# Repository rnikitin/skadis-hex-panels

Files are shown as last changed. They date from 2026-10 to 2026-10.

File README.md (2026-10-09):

# Hexagonal SKÅDIS-compatible panels



**Start in [PRINT_THIS](PRINT_THIS/README.md).** This folder contains only the current printable version. Earlier prototypes are under `archive/`.

| File | Use |
|---|---|
| [S01_complete_kit_PETG_P2S.3mf](PRINT_THIS/S01_complete_kit_PETG_P2S.3mf) | Ready Bambu Studio project: two panels, eight mounts and one flat jig |
| [S01_panel_PLA_P2S.3mf](PRINT_THIS/S01_panel_PLA_P2S.3mf) | Ready Bambu Studio project for the identical panel in PLA |
| [S01_panel.stl](PRINT_THIS/S01_panel.stl) | Hex panel |
| [S01_wall_mount_2p2.stl](PRINT_THIS/S01_wall_mount_2p2.stl) | Wall mount for the selected 3 × 16 mm self-tapper |
| [S01_alignment_jig_5p2.stl](PRINT_THIS/S01_alignment_jig_5p2.stl) | Flat removable jig, 5.2 mm fit and 4.4 mm insertion depth |

All plates print without supports. See [assembly](docs/assembly.md), [hardware](docs/hardware.md), and [STEP models](cad/) for details.

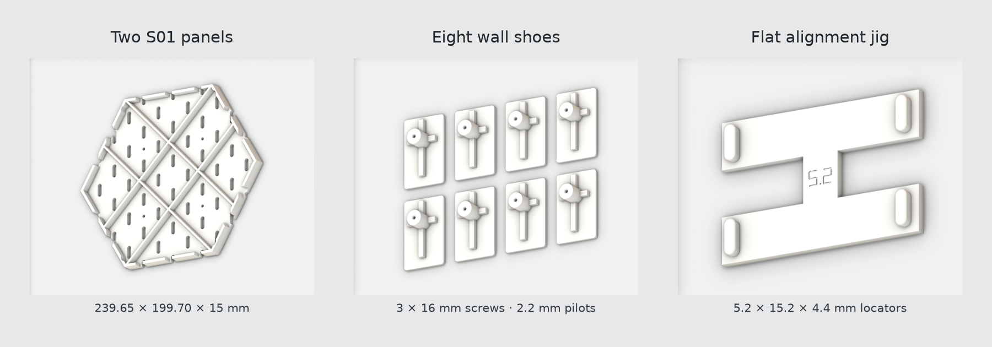
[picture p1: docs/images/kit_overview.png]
Current print kit


## Panel renders

| Front | Rear, tilted to show all four ribs |
|---|---|
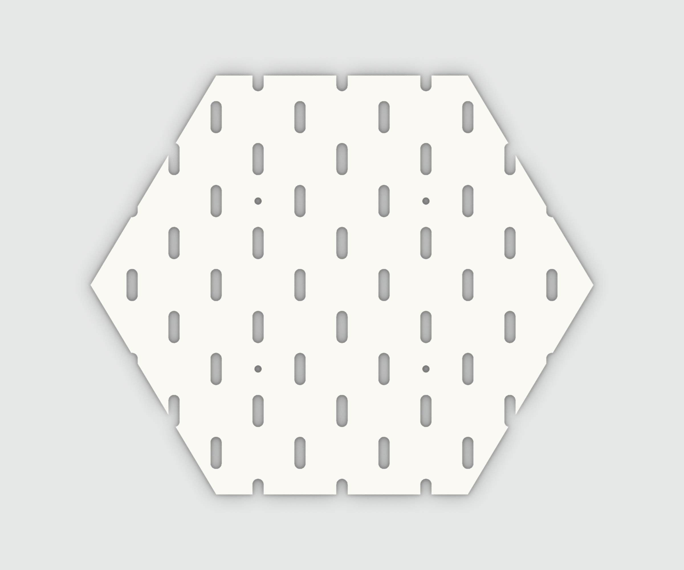
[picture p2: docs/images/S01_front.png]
One S01 panel from the front
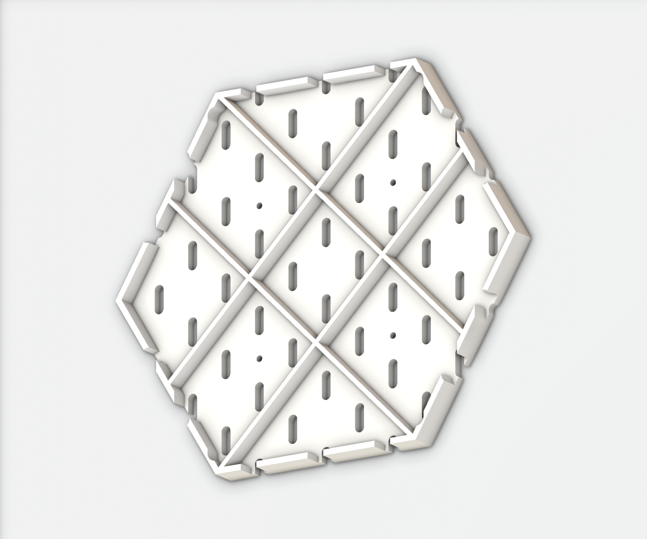
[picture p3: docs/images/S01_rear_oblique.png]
S01 rear ribs at an oblique angle
|  |  |

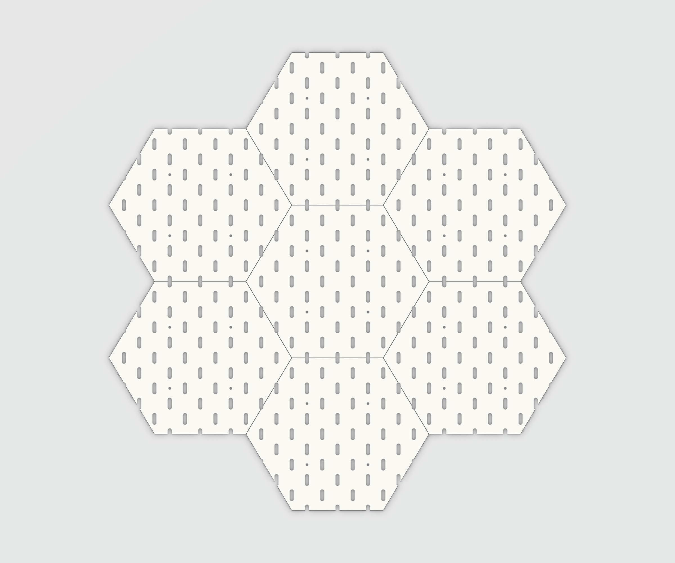
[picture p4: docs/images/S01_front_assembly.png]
Seven S01 panels joined on the same slot lattice


Matte-white studio renders of the final printable STL geometry. The seven-panel layout uses the nominal 0.3 mm seams, with subtle edge accents for visibility at smaller display sizes. Full-resolution images are in `docs/images`.

Each panel is approximately **239.65 × 199.70 × 15 mm**. Panel faces are 5 mm thick; slots are 5.3 × 15.3 mm. Current slicer settings are 0.2 mm layers, four walls and 100% infill. Each PETG panel estimates 6 h 45 min / 239 g. PLA and PETG projects are separate because the installed command-line slicer failed on a combined-material run. Both delivered projects were successfully sliced and checked.

Print one or two panels in the chosen material, then the PETG hardware plates. The PLA project is an alternative to a PETG panel plate. No additional small calibration print is required for this iteration.

## Build from source

Python 3.12 is the supported baseline:

```sh
uv sync --extra dev
uv run skadis-hex build --output build/full-kit
uv run skadis-hex validate --output build/full-kit
uv run pytest -q
# Requires a separately installed Bambu Studio:
uv run skadis-hex slice --output build/full-kit
```

The build produces three STL parts, STEP parts and mounted assemblies, geometry-only 3MFs and dimension records. Slicing produces the native PETG and PLA projects, plate previews and verification reports. Use `--slicer /path/to/BambuStudio` on other installations. No command sends a print job.

Alternatively, install the package with `python -m pip install -e '.[dev]'` in a Python 3.12 virtual environment.

## Verification status

| Item | Status |
|---|---|
| Continuous slot lattice and two-row spacing | Checked geometrically |
| Connected watertight full-kit meshes | Checked |
| Six jig seam placements, short locators and screw-head clearance | Checked geometrically |
| Native PETG/PLA material assignments, supports, plate bounds and toolpaths | Checked |
| 5.2 mm PETG fit strip | Selected by the user after printing |
| Increased jig depth and four-point fit | Full-size print pending |
| Selected 2.2 mm screw pilot | User-selected; full assembly test pending |
| Accessory insertion, tape on wallpaper and full-panel load rating | Not yet established |

The historical 3 kg / 100 mm study used earlier geometry and idealized PLA/support conditions. It is not a load rating for the current panel or adhesive mounting.

## Project map and history

```text
PRINT_THIS/           Current STL and ready Bambu Studio files only
cad/                  Current STEP parts and mounted assemblies
verification/current/ Checks, previews and SHA-256 manifest
src/skadis_hex/       Parametric geometry and build/slicing tools
docs/                 English printing, hardware and design documentation
archive/              Superseded prototypes and experiments
analysis/v3/          Historical stiffness comparison
```

The rear-open hidden key failed its PETG retention test and was abandoned. Read the [fit report](docs/fit_reports/2026-10-09-hidden-key-retention.md) and [design history](docs/history.md). To reproduce that geometry, use `legacy-build`, `legacy-validate` and `legacy-slice` with a separate output directory; ordinary `build/validate/slice` commands now target the full kit.

All dimensions are millimetres. Source geometry is independently generated; [references](docs/references.md) list the inspiration and technical sources.

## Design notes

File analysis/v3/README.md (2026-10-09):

# Historical v3 stiffness study

This is a record of the earlier v3 geometry with four adhesive shoes and front-access seam-bridge receiver features. The current hidden-joint v2 panel has different perimeter relief and receivers. These results do not establish a load rating for the current geometry or adhesive attachment.

## Model

- Three-dimensional isotropic linear elasticity, quadratic P2 tetrahedra.
- Young's modulus 2000 MPa, Poisson's ratio 0.35, assumed solid density 1.24 g/cm³.
- A 3 kg accessory whose centre of gravity is 100 mm from the wall, plus estimated self-weight.
- Face-to-wall distance 24 mm including an assumed 1 mm tape thickness.
- Weight applied around slots and an out-of-plane force couple with a 40 mm row spacing.
- Panel-to-shoe contacts bonded; four 30 × 50 mm tape footprints fixed rigidly.
- Screw contact/preload, adhesive/wall compliance, creep, printed anisotropy, individual hook contact and failure were excluded.

## Recorded results

| Accessory position | Maximum out-of-plane displacement |
|---|---:|
| Near the centre | 0.185 mm |
| Side area | 0.366 mm |
| Upper edge | 1.114 mm |

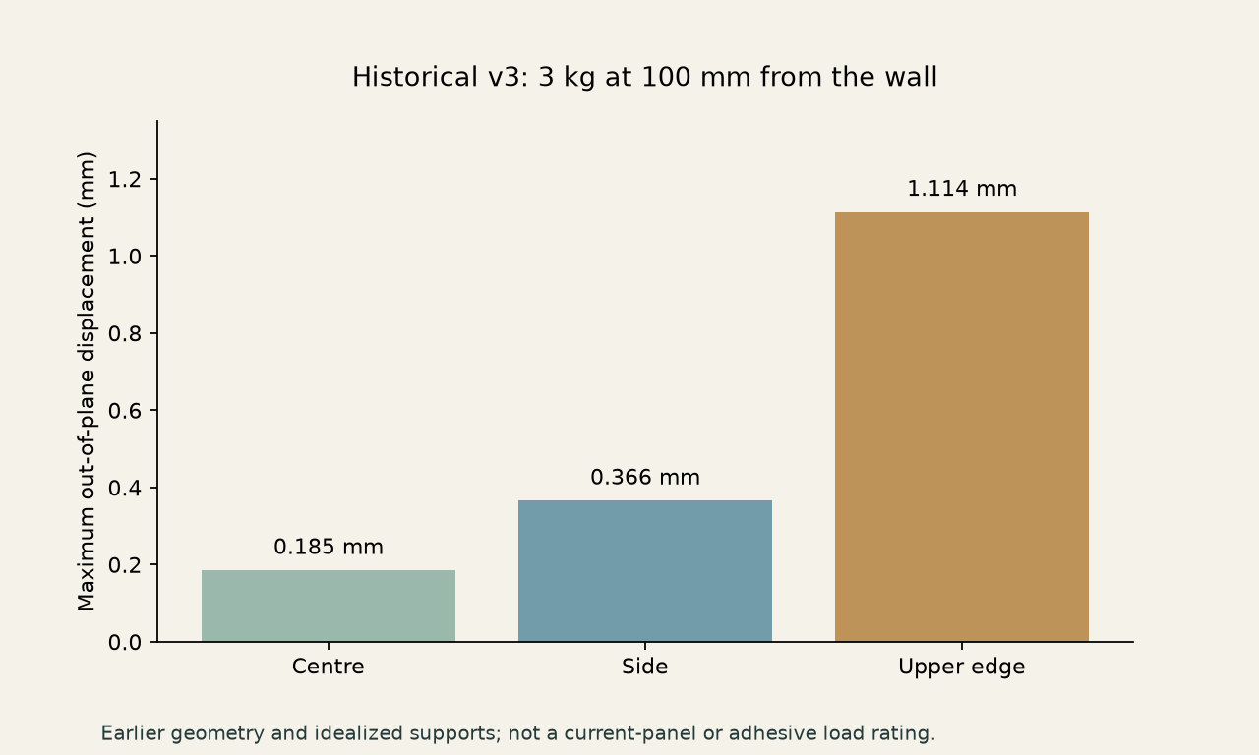
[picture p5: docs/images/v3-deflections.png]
Historical v3 deflections


For the side case, changing P2 mesh size from 5 to 3.5 mm changed the maximum from 0.3527 to 0.3658 mm (3.60%). The upper case changed from 1.1073 to 1.1140 mm (0.60%). The central case did not have its own mesh-refinement study.

A 60 × 10 × 6 mm cantilever under a 10 N load produced 1.9849 mm compared with 2.0162 mm from a beam estimate including shear (1.55% difference). Solver residuals, force balance and moment balance were checked. This verifies numerical consistency, not physical calibration of printed PLA.

Adding two longitudinal ribs to the four-diagonal design reduced the side-case maximum by about 30% in the corresponding comparison. The four-diagonal option was selected as the next physical prototype; it was not proven to be the unique optimum.

## Reproduce

Install optional solver dependencies and run from the repository root:

```sh
uv sync --extra analysis
uv run python analysis/v3/solver.py --benchmark --order 2
uv run python analysis/v3/solver.py --variant diamond --h 3.5 --case edge --mounted --order 2
uv run python analysis/v3/solver.py --variant diamond --h 3.5 --case top --mounted --order 2
```

Exact input STEP files and hashes are under `inputs/`. Recorded result summaries are under `results/`; reruns and numerical field arrays are written to `build/analysis-v3` by default. Pass `--output` to change that directory. Large field arrays are not tracked in Git.

The analysis was developed using Gmsh, scikit-fem and PyAMG; sources are linked in [references](../../docs/references.md).

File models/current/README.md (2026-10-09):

# Current prototype files

This directory contains the reviewed CAD exports and generated Bambu Studio test project for hidden joint v2 (24 × 8 × 3.2 mm key), plus the accepted M4 wall shoe.

- `projects/corner_fit_test_24x8x3p2_P2S.3mf`: first physical test, three fragments and four keys.
- `stl/`: individual current test parts and the wall shoe.
- `step/`: full prototype panel, three-panel assembly and wall shoe for inspection.
- JSON files: dimensions, geometry checks, coupon crop, slicer result and file hashes.

The full panel STEP is a development model. A full printable current-panel STL has not been released. Geometry checks and slicer success do not establish physical snap fit, hook compatibility or adhesive capacity.

To regenerate, run `skadis-hex build --output build/current`, then validate and optionally slice as described in the root README. Rebuilding may change STEP headers and mesh ordering while preserving geometry.

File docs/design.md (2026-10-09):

# Current S01 design

## Shared lattice and contour

Slot centres use `x = 20 i + 20`, `y = 40 j + 20 (i mod 2)`. Tile translations `(180,100)` and `(0,200)` preserve this lattice, including 40 mm vertical spacing for two-row accessories.

The nominal 240 × 200 mm hex has vertices `(120,0), (60,100), (-60,100), (-120,0), (-60,-100), (60,-100)`. A 0.15 mm inward contour offset produces a 0.3 mm nominal seam without changing centre positions. Actual bounds are approximately 239.65 × 199.70 mm. The panel is symmetric and can rotate by 180°.

Working slots are 5.3 × 15.3 mm capsules. Boundary slots are completed by the neighbouring tile; no lattice positions are shifted or deliberately omitted near a seam.

## Structure

The face is 5 mm thick. Four 2.4 mm wide diagonal ribs follow `x+y=±40` and `x−y=±40`, reaching depth 15 mm from the front face. The perimeter rib is 3.2 mm wide and reaches the same rear plane.

Perimeter reliefs are local 9.3 × 25.3 mm capsules, allowing 2 mm around the working slot plus 3 mm additional vertical travel in both directions. Mirroring this allowance preserves 180° use. The actual hook body and downward insertion movement remain part of the full-size physical test.

There are no key receivers, retaining lips, dowel sockets or connector pads in the current panel. Four separate 3.4 mm mounting holes at `(±40,±40)` keep working SKÅDIS slots available.

## Wall mounting

Each panel has four independent PETG shoes. The selected 2.2 mm blind pilot accepts the user's nominal 3 × 16 mm self-tapper as a thread-forming assembly. The adhesive plane is 23 mm behind the panel face. See [hardware](hardware.md) for the screw stack and orientation.

## Removable alignment jig

The 92 × 60 × 4 mm body consists of two horizontal bars and a central spine. Four locators occupy an 80 × 40 mm rectangle. The user selected 5.2 mm width from the PETG strip trial; locator length is 15.2 mm. The full kit increases projection from 3.5 to 4.4 mm, retaining 0.6 mm before the panel's rear face.

The jig is one flat printable solid. It sits directly on the bed with the locators upward and needs no supports. A pull-knob variant was rejected because of its support requirements.

The same jig fits all six seam directions with vertical locators. Each placement uses two complete slots per panel. Its planar body clears the selected screw heads by at least 7.55 mm. The tool withdraws straight forward and leaves no hardware in the slots.

## Evidence boundaries

CAD checks cover connected watertight meshes, symmetry, open slots, shoe collisions, six seam placements and 18 insertion poses. Native Bambu projects have verified material assignments, support settings, plate bounds, object counts and generated toolpaths.

The 5.2 mm PETG strip is the physically selected fit. The deeper flat jig, selected screw pilot, full panel, accessories and adhesive mounting remain the next physical test. No new structural load rating is claimed. Superseded key geometry remains available through the `legacy-*` commands and archived release files.

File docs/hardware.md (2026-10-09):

# Hardware for the current full-size kit

| Item | Per panel | Two panels | Specification |
|---|---:|---:|---|
| Printed wall shoe | 4 | 8 | PETG, 2.2 mm blind pilot |
| Pointed self-tapping screw | 4 | 8 | 3 × 16 mm under-head length, head Ø4.9 × 3 mm |
| Adhesive strip | 4 | 8 | 30 × 50 mm, fitted to a 34 × 54 mm base |
| Removable alignment jig | 1 shared | 1 shared | PETG, 5.2 × 15.2 × 4.4 mm locators, flat support-free body |

These are the black socket-head self-tappers in the user's product diagram. The seller's `M3` label does not imply an ISO metric machine thread. No M4 nut, washer or permanent inter-panel connector is used in the current kit.

## Screw and shoe stack

- Panel face: 5 mm thick, with a 3.4 mm screw clearance hole.
- Shoe post: 12 mm diameter, with a 2.2 mm pilot and a lead-in at its front.
- Screw: 16 mm under the head, including the point; 11 mm enters the shoe through the panel.
- Screw tip: depth 16 mm from the panel face.
- Blind pilot floor: depth 18.5 mm, giving 2.5 mm nominal tip clearance.
- Adhesive surface: depth 23 mm, giving 7 mm between the tip and the adhesive.
- Head bearing margin: (4.9 − 3.4) / 2 = 0.75 mm radially.

The pilot was selected by the user for the full assembly print, without another separate pilot trial. Actual insertion torque, printed hole size and retention have not been measured. Use controlled hand tightening through the panel.

## Shoe orientation

The adhesive-base centroid is offset 8 mm from the screw. Orient this offset upward on the upper shoes and downward on the lower shoes. The footprint is 34 × 54 mm, with a 30 × 50 mm tape area. Four strips provide 60 cm² adhesive area per panel.

The planned surface is wallpaper and the tape specification is unverified. No adhesive capacity is assigned by these dimensions.

The legacy M4 shoe and the earlier 2.2 / 2.4 / 2.6 calibration parts remain in historical directories. Use `wall_shoe_3x16_pilot_2p2.stl` from [the full kit](../PRINT_THIS) for this build.

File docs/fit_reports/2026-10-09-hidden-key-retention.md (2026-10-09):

# Hidden-key print feedback — 2026-10-09

## Observed outcome

The user reports that the printed key falls out of the rear-open receiver easily, does not seat tightly, and allows the board assembly to wobble. The current retention design has failed its physical fit test. The user is comfortable reducing the key length.

The user confirmed the v2 (24 × 8 × 3.2 mm) trial was printed in PETG. Actual key and receiver dimensions have not been measured. A simpler closed-socket dowel was briefly considered, then the user abandoned permanent inter-panel connections.

## Verified design facts for v2

- Key neck width: 4 mm.
- Peak retaining throat: 3.8 mm, giving only 0.1 mm nominal overlap per arm.
- Receiver-outline allowance: 0.25 mm per side.
- Retainers are small triangular ramps rather than a continuous rear capture shelf.
- Ramp depth range: 12.5–13.2 mm, with the maximum projection at 12.85 mm.
- The supplied slicing profile uses 0.2 mm layers.

Ideal section sampling at layer mid-planes 12.7/12.9/13.1 mm reaches approximately 0/0.05/0 mm overlap. This is an analysis of the CAD ramp and layer sampling, not a measurement of the actual printed extrusion boundary.

## Current hypothesis and next evidence

The nominal capture is too small to be robust to the slicing and printed dimensions; the generous receiver clearance separately explains part of the play. This hypothesis has not yet been confirmed by measuring the actual print.

The selected next direction is a [removable front alignment jig](../front-alignment-jig.md). Each panel remains independently mounted. The failed key and its receiver are preserved as historical prototypes; their retention redesign is no longer planned.

The existing CAD tests only establish a possible insertion envelope under prescribed arm deformation. They do not validate holding force. No replacement connection is released by this report.

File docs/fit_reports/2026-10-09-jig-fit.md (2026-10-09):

# Front-jig fit feedback — 2026-10-09

The user selected the **5.2 mm** PETG width strip: it fit more closely than the smaller candidates. No measured insertion force or printed dimensions were supplied.

The next full-size kit keeps the 5.2 × 15.2 mm capsule section and increases locator depth from 3.5 to 4.4 mm. A pull knob was added at the user's request, then removed because it required excessive supports. The current jig has a flat 4 mm body and prints without supports.

The user selected the smallest proposed wall-shoe pilot, **2.2 mm**, for the purchased nominal 3 × 16 mm self-tappers and requested no further separate calibration print. Full-panel printing and assembly are the next physical test.

Panels will be printed in both PLA and PETG; shoes and jig use PETG. The accepted strip fit is evidence for the PETG width choice, not proof of the deeper jig fit on both panel materials or screw retention.

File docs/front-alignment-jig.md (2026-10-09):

# Historical front-jig width trial

The user selected the **5.2 mm** PETG strip. The current [full-size kit](assembly.md) uses a flat jig with 4.4 mm-deep locators and no handle or supports. The original trials below remain reference files; printing them again is not required.

The next print is the [three-strip PETG fit trial](../archive/prototypes/alignment_fit/projects/front_jig_fit_strips_P2S_PETG.3mf). Estimated on P2S with a 0.4 mm nozzle: **32 minutes and 15.71 g**. The project has been sliced; no physical fit has been verified.

## First print and selection

1. Print the three labelled strips in PETG at 100% scale, flat body face down and locators upward. The project uses 0.2 mm layers, four walls, 100% infill, no supports and the installed Generic PETG P2S material preset (255 °C nozzle, 70 °C textured plate). Use settings appropriate to the actual spool if different.
2. On an existing printed panel or test fragment, choose two complete slots in one column, 40 mm centre-to-centre. Do not use slots split by a seam. Support the panel by hand while testing.
3. Start with **4.9**, then try **5.1** and **5.2**. The number is the locator width in millimetres; its overall capsule length is the number plus 10 mm. Both locators must enter simultaneously until the strip's flat back touches the panel face.
4. Select the largest candidate that slides in by hand, has little lateral play and pulls out easily. Do not use a press fit or force a stuck strip. If all are tight or all are loose, report that result before printing the full jig.
5. Report each strip as **loose / sliding fit / tight**, and whether it seats flat and removes easily.

The nominal slot is 5.3 × 15.3 mm. These candidates leave 0.4, 0.2 or 0.1 mm total dimensional clearance respectively, before printing error. The 5.1 mm candidate is provisional, not an already selected fit.

## Full jig after the strip test

Matching full-jig STLs are in [the archived width-trial STLs](../archive/prototypes/alignment_fit/stl): `front_jig_4p9.stl`, `front_jig_5p1.stl`, and `front_jig_5p2.stl`. Print only the selected size.

The body is 92 × 60 × 4 mm: two horizontal 20 mm bars and a 16 mm central spine. The four vertical capsule locators form an 80 × 40 mm rectangle and project 3.5 mm from the seating face, with a 0.4 mm tip lead-in. At full seating they remain 1.5 mm short of the rear of the 5 mm panel face. There are no hooks, rear locks or permanent panel pockets.

Before adhesive mounting, test the full jig on two supported panels across both a horizontal and a sloping seam. A two-point strip checks local fit and a 40 mm pitch, but does not establish the four-point fit over 80 mm. All four locators must engage, both panel faces must seat against the jig, and the jig must withdraw easily without moving the panels.

The six nominal placements have two complete slots per panel and at least 7.55 mm clearance from the purchased 4.9 mm screw heads. The locators stay vertical for every seam; do not rotate the jig by 90°.

## Wall positioning

Keep each panel on its own four wall shoes. Bring the new panel close to its intended plane, engage the jig with both panels while supporting the new panel, and align the lattice before the adhesive touches the wall. Press the shoes onto the wall, hold the panels in position and withdraw the jig straight forward by its central spine or edges.

This tool is an alignment aid; it does not suspend the new panel or establish adhesive capacity. After removal all working slots are available again. The separate [3 × 16 mm wall-shoe pilot trial](self-tapping-3x16.md) remains necessary before choosing a pilot diameter.

## Regeneration

```sh
uv run skadis-hex jig-fit --output build/alignment-fit
uv run skadis-hex slice-jig-fit --output build/alignment-fit
uv run pytest -q
```

`slice-jig-fit` defaults to PETG. Use `--material PLA` only if the physical trial will use PLA. Core geometry 3MF files carry no printer settings; the named `P2S_PETG` project contains the verified slicer settings. STL/STEP, parameters, mesh checks, placement evidence and slicing statistics are retained in the trial directory.

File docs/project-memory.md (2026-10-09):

# Project operating notes

- Use one material per native project with the installed Bambu Studio 02.08.02.61 CLI. A four-plate run with PLA in filament slot 1 and PETG in slot 2 crashes in nozzle-group lookup; `kit_printing.py` produces the all-PETG kit and a separate PLA panel. Each material is mapped to the single P2S extruder.
- Bambu Studio can save over an opened 3MF and remove cached toolpaths or change its settings. Before publishing a saved project, validate the embedded G-code, material, object counts and supports, then refresh the manifest. Preserve locally saved variants before restoring historical generated files.
- The accepted jig locator width is 5.2 mm from a PETG strip. Current depth is 4.4 mm; the body is flat and support-free. Increased depth/full four-point fit remains a full-kit physical test, not part of the already reported strip result.

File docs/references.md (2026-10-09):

# References

Reference models were used for comparison and design discussion. The repository's panel geometry is independently generated from parameters; no third-party STL/3MF downloads were incorporated.

## Panel inspiration

- [Hexagonal SKADIS Type Board v2](https://makerworld.com/en/models/1595031-hexagonal-skadis-type-board-v2)
- [IKEA SKADIS Easy Install](https://makerworld.com/en/models/2419153-ikea-skadis-easy-install)
- [SKÅDIS generator dimensional reference](https://marketplace.autodesk.com/apps/880f2e71-a0b1-41ec-b148-294452d2419c)

## Wall-mount concepts

- [Wall mount without screws — tape](https://makerworld.com/en/models/727961-ikea-skadis-wall-mount-without-screws-use-tape)
- [Wall mount on tape](https://makerworld.com/en/models/1510374-ikea-skadis-wall-mount-on-tape-without-screws)
- [No-screws wall-mount collection](https://makerworld.com/en/models/2839270-skadis-wall-mount-no-screws-collection)
- [Infinite Lightweight hybrid wall mount](https://makerworld.com/en/models/3004055-infinite-lightweight-skadis-hybrid-wall-mount)

The referenced mounts are mechanism examples, not drop-in compatibility claims for this project.

## Tools and engineering references

- [CadQuery](https://cadquery.readthedocs.io/)
- [Gmsh](https://gmsh.info/doc/texinfo/)
- [scikit-fem linear elasticity example](https://github.com/kinnala/scikit-fem/blob/master/docs/examples/ex11.py)
- [Covestro snap-fit design guide](https://solutions.covestro.com/-/media/covestro/solution-center/brands/downloads/imported/1557216102.pdf)
- [3M VHB technical resources](https://www.3m.com/3M/en_US/vhb-tapes-us/resources/)

## Alignment discussion and native project generation

- [Skådis connector](https://makerworld.com/en/models/1880134-skadis-connector)
- [Infinite seamless modular SKÅDIS boards](https://makerworld.com/en/models/1708043-infinite-seamless-modular-skadis-boards)
- [Bambu Studio assembly-list interface](https://github.com/bambulab/BambuStudio/blob/master/src/BambuStudio.hpp)

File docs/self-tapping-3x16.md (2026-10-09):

# Historical 3 × 16 mm self-tapping screw fit trial

The current [full-size kit](assembly.md) uses the user-selected 2.2 mm pilot. No further small pilot print is required before that kit; the candidate trials below remain historical reference.

The user-selected black socket-head screw has these nominal dimensions in the supplied product diagram:

| Dimension | Nominal value |
|---|---:|
| Major thread diameter | 3 mm |
| Length under the head, including point | 16 mm |
| Head diameter | 4.9 mm |
| Head height | 3 mm |

This is a coarse pointed self-tapper. The seller's `M3` label does not establish an ISO metric nut fit. Thread pitch, driver size and actual batch tolerances have not been supplied.

## Candidate wall mount

The outer shoe shape is preserved: 34 × 54 mm base, 30 × 50 mm tape area, 12 mm post diameter and 23 mm from panel face to adhesive surface. The post is solid except for a blind pilot bore; the M4 nut pocket and side channel are removed.

Use a 3.4 mm mounting clearance hole in the panel instead of the released 4.5 mm hole. With a 4.9 mm head, the radial bearing ledge increases from 0.2 to 0.75 mm; the nominal annular bearing area is about 9.78 mm². There is no washer in the trial. The head protrudes approximately 3 mm from the panel face. Its physical bearing and clamping performance still require a print test.

The 5 mm panel leaves 11 mm of the screw inside the shoe, including its point. The screw ends at depth 16 mm; the blind pilot ends at 18.5 mm and the adhesive surface is at 23 mm. Nominal clearances are 2.5 mm to the pilot floor and 7 mm to the adhesive. These are geometric clearances, not a pull-out load rating.

## Choose the pilot by testing

Three candidates are provided: **2.2, 2.4 and 2.6 mm**. The 2.4 mm bore is only a starting trial, not a physically selected final diameter. Actual printed holes and the screw's thread profile determine the useful fit. Manufacturer guidance recommends material-specific pilot design and prototype assembly tests; these candidates are not a manufacturer specification for this unidentified screw or printed PLA. [Bossard construction recommendations](https://www.bossard.com/-/media/bossard-group/website/documents/technical-resources-old/construction-recommendations.pdf).

The test project contains:

- A three-post block with large 5 mm-high engraved pilot labels.
- A separate 5 mm plate with matching 3.4 mm clearance holes.
- One complete candidate wall shoe with a 2.4 mm pilot.
- A panel fragment with a 3.4 mm mounting hole and two complete working slots 40 mm apart, for checking an actual two-row accessory and head clearance.

A smaller pilot-only project contains just the three-post block and 5 mm plate. Use it first to select a bore without printing a complete wall shoe.

[Download the pilot-only test](../archive/prototypes/screw_pilot_fit/projects/self_tapping_3x16_pilot_test_P2S.3mf) — about 40 minutes / 21.42 g. The [complete trial](../archive/prototypes/screw_pilot_fit/projects/self_tapping_3x16_fit_P2S.3mf) is about 1 h 21 min / 47.58 g.

Test the screw **through the 5 mm plate**. The bare 16 mm screw is longer than the 13.5 mm pilot depth and must not be driven fully into an uncovered test post. Use controlled hand tightening. Start with 2.4 mm; compare the other fresh bores if it is too tight or does not hold. Check cracking, seating, stripping and repeated removal before selecting the final shoe. No torque or load rating is assigned from the product image.

The test-block post orientation, 12 mm diameter, lead-in and blind depth match the corresponding wall-shoe features. Its base is a test fixture, not an adhesive mount.

## Build and slice

```sh
uv run skadis-hex screw-fit --output build/self-tapping-fit
uv run skadis-hex slice-screw-fit --output build/self-tapping-fit
# Smaller first test:
uv run skadis-hex slice-screw-fit --output build/self-tapping-fit --pilot-only
```

The current `build` command produces the full-size kit with the selected 2.2 mm self-tapping shoe. The published v0.1.0 files and `legacy-build` retain the M4 reference. `joints.panel(wall_hole_diameter=3.4)` generates the matching candidate panel geometry; its default 4.5 mm hole remains unchanged for reproducibility.

The shape and nominal dimensions have been checked in CAD. Physical fit, pull-out resistance, long-term retention and adhesive/wall strength remain unverified.

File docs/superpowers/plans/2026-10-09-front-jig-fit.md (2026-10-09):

# Front alignment jig fit trial implementation plan

> **For agentic workers:** Execute this bounded CAD task inline, with geometry tests and native slicer verification. User approved the displayed open-front jig concept on 2026-10-09.

**Goal:** Deliver a small PETG fit trial and matching full jig variants for independently mounted S01 panels.

**Architecture:** Add an independent alignment module using the existing lattice, CAD helpers, STL export conventions and core-3MF plate writer. Preserve superseded key geometry as historical data; the new jig never needs a panel pocket or rear access. Extend the shared slicer entry point to select and verify PETG explicitly.

**Tech stack:** Python 3.12, CadQuery 2.8, Shapely 2.2, trimesh 5.1, Bambu Studio P2S 0.4.

## Constraints

- Repository documentation is English.
- Full jig: 92 × 60 × 4 mm body; two 20 mm horizontal bars and a 16 mm central spine.
- Four vertical capsule locators, 80 × 40 mm centre spacing, 3.5 mm projection.
- Candidate widths 4.9, 5.1, 5.2 mm; capsule overall length equals width + 10 mm.
- Locator tips have a 0.4 mm lead-in; the constant locating section stays at the named size.
- Calibration strips: 16 × 60 × 4 mm, two locators spaced 40 mm, engraved numeric width.
- Print flat body face down, locators up, without supports or XY scaling.
- Sliding fit and physical alignment remain unverified until the user's print test.

## Task 1: Geometry and fit evidence

Files: `src/skadis_hex/alignment.py`, `tests/test_alignment.py`, `src/skadis_hex/cli.py`.

Interfaces: `make_jig(width)`, `make_fit_strip(width)` return one CadQuery solid; `verify_placements()` returns all six lattice placements; `build(output)` writes STL, STEP, geometry 3MF and JSON evidence.

- [x] Write tests first: validate connected solids and dimensions, sample the locating cross-section below the lead-in, verify each placement uses two whole slots per panel, and assert at least 7.5 mm clearance from purchased 4.9 mm screw heads.
- [x] Run `work/.venv/bin/python -m pytest tests/test_alignment.py -q`; expect missing module before implementation.
- [x] Implement the two-bar outline as the union of `box(-46,-30,46,-10)`, `box(-46,10,46,30)`, `box(-8,-10,8,10)`. Extrude 4 mm and add vertical capsules at `(±40,±20)`. Use the same locator builder for the two-point strip at `(0,±20)`.
- [x] Export three strips and three full jigs. Put only the strips on the first test plate. Write all-six-edge placement coordinates, physical-fit status and mesh integrity to JSON.
- [x] Run the new geometry tests and complete build; expect valid connected solids and watertight meshes for all six parts.

## Task 2: PETG project and delivery

Files: `src/skadis_hex/printing.py`, `src/skadis_hex/print_profiles/filament_petg.json`, `docs/front-alignment-jig.md`, `models/alignment_fit/`, README and history.

Interfaces: `slice_geometry_project(..., material='PLA')` preserves PLA behavior; material `PETG` selects a fully resolved installed-vendor profile and checks exported material metadata.

- [x] Resolve the installed Generic PETG P2S parent/include chain; verify PETG type, 1.27 density and 255 °C nozzle / 70 °C textured plate settings from vendor files.
- [x] Add `jig-fit` and `slice-jig-fit` CLI actions. Slice the three-strip geometry plate with PETG and preserve separate named validation/preview outputs.
- [x] Verify the exported 3MF contains PETG in both project metadata and G-code, 0.2 mm layers, four walls, 100% infill, and no supports.
- [x] Run all package tests, inspect the plate preview, document first-print selection criteria and the later full-jig check across two panels.
- [x] Record the superseded key trial and current removable-jig direction, copy checked files into `models/alignment_fit`, commit and update the existing public-repository branch.

## Delivery boundaries

The first print contains calibration strips only. A successful two-point strip does not by itself validate all four locators over 80 mm, so the selected full jig must be tried dry on two panels before applying adhesive. Every panel remains independently mounted. Wall-shoe pilot selection remains a separate pending physical test.

## Outcome

Six connected, watertight parts exported. All six seam placements pass. The package suite passes 16 tests, including straight front withdrawal and a PETG material regression. Native P2S PETG toolpaths estimate 32m17s / 15.71 g; labels were inspected in the generated plate preview. Physical fit remains pending. Public branch update is recorded by the commit containing this plan.

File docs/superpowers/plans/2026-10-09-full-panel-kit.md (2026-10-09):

# Complete S01 test-print kit

Approved scope: prepare full-size panels for PLA and PETG, PETG wall shoes with the user-selected 2.2 mm pilot, and a flat PETG front jig using the physically selected 5.2 mm locator width. No further calibration print is required before this kit.

- [x] Build the clean 240 × 200 mm nominal S01 panel: 5 mm face, four 2.4 × 10 mm diagonals, 3.2 mm perimeter with local hook relief, four 3.4 mm mounting holes, no legacy receivers.
- [x] Keep the earlier 3.5 mm-deep jig/strips reproducible. Add the working flat jig with 4.4 mm locators. The user removed the pull-knob requirement; print flat on the bed with locators upward and no supports.
- [x] Export panel, selected shoe and handled jig as connected STL/STEP. Build the mounted panel and two-panel STEP assembly.
- [x] Verify symmetry, the global lattice at all six seams, open working slots, former pocket removal, shoe/post and screw clearances, and front jig insertion/withdrawal.
- [x] Produce the native all-PETG kit with two panel plates, eight shoes and a flat jig, plus an identical standalone PLA panel project and check toolpaths, material assignments, support settings, bed boundaries and object counts.
- [x] Update English assembly/hardware documentation and current-file pointers, retain legacy history, push checked outputs to the existing public repository, and complete CI.

The selected 5.2 mm fit was reported satisfactory on the PETG strip. Increased depth and the four-point flat jig have not yet been printed. The 2.2 mm pilot is a user-selected nominal dimension, not a measured screw-retention result. This kit is the next full-size physical test.

## Outcome

The project was moved to `~/projects/skadis-hex-panels`; the previous path is a compatibility symlink. Twenty package tests pass. A fresh build passes all geometry/mesh checks and native material, object-count, support and toolpath checks. The release contains a support-free flat jig and separate material projects. User-saved older Bambu projects were preserved locally.

The combined PLA/PETG CLI run failed in the installed slicer’s second-filament nozzle-group lookup. The delivered single-material projects were generated by Bambu Studio without patching G-code.

## Delivery layout

`PRINT_THIS` contains exactly the final three STL files, two ready Bambu projects and a short README. Current STEP lives in `cad`, evidence in `verification/current`, and previous printable prototypes in `archive/prototypes`. The root README links to each current print file before technical details. A delivery check verifies this layout, hashes and native cached toolpaths in CI.

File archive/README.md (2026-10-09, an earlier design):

# Archived experiments

`experiments/` preserves earlier generator/validation source and numerical reports. These files record the design history; they are superseded by the current package.

The original sibling-directory layout is retained where historical scripts import one another. Some scripts write generated files next to their source. Use the current CLI for active development.

Earlier human-language reports have been replaced by the English summaries in [design history](../docs/history.md) and [analysis](../analysis/v3/README.md). Raw solver field arrays, duplicate archives, scratch environments and machine-local logs are excluded from version control; they can be regenerated from the retained inputs and solver.

Archived STL files are not compatible with the current hidden-joint receivers unless explicitly stated. The initial S01/S02/S06 and small rear-key experiments remain useful comparison material.

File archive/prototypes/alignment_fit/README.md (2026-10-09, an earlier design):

# Historical front alignment jig trial

The user selected 5.2 mm. Current print files are in the [full-size kit](../../../PRINT_THIS/README.md).

Start with `projects/front_jig_fit_strips_P2S_PETG.3mf`: three labelled two-locator strips, about 32 minutes / 15.71 g PETG on P2S 0.4. Select a sliding fit on an existing printed panel before printing the matching `stl/front_jig_*.stl`.

See the [English test and assembly guide](../../../docs/front-alignment-jig.md). The full four-point jig must be tested dry across a horizontal and an oblique seam. Physical fit remains unverified.

- `stl/`: three strips and three full jig sizes, flat body face at z=0 for printing.
- `step/`: editable inspection solids in their design coordinates.
- `projects/*_geometry.3mf`: geometry only, without printer presets.
- `projects/*_P2S_PETG.3mf`: native sliced project with the verified PETG profile.
- `parameters.json`: dimensions, mesh integrity and all-six-edge placement evidence.
- `*_slicing.json`: actual slicer statistics and material checks.
- `manifest.json`: SHA-256 hashes of the delivered files.

These are placement tools, not permanent panel connectors or load-bearing wall hardware.

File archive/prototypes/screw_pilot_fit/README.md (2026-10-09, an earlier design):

# Nominal 3 × 16 mm self-tapping wall-mount trial

Start with `projects/self_tapping_3x16_pilot_test_P2S.3mf`: about **40 minutes / 21.42 g PLA**. It contains a three-post pilot block (2.2 / 2.4 / 2.6 mm, large engraved labels) and the separate **5 mm test plate**.

Drive the actual screw through that plate into a fresh pilot. Do not fully drive a bare 16 mm screw into the uncovered 13.5 mm-deep pilot. Begin with 2.4 mm and compare the other candidates as needed, using controlled hand tightening. Check seating, cracking, stripping, retention and repeated removal.

`projects/self_tapping_3x16_fit_P2S.3mf` is the larger complete trial, approximately **1 h 21 min / 47.58 g**. It adds a candidate shoe with a 2.4 mm pilot and a panel fragment with two complete SKÅDIS slots and a 3.4 mm mounting clearance hole.

Three complete shoe STL variants are included for choosing the pilot after testing. The 2.4 mm candidate is provisional; physical fit has not been checked.

The supplier diagram gives a 3 mm major diameter, 16 mm under-head length, and 4.9 mm diameter × 3 mm high head. Through the 5 mm panel, 11 mm enters the shoe including the point. There is 2.5 mm clearance below the tip and 7 mm to the adhesive surface.

This shoe has no metal nut pocket. It is a separate variant from the released M4 nut shoe. The small head is intended for the matching 3.4 mm mounting hole, rather than the released 4.5 mm hole.

See [full fit instructions](../../../docs/self-tapping-3x16.md). `parameters.json` records nominal dimensions and unresolved physical checks; `print_metrics.json` identifies the statistics for each sliced project.

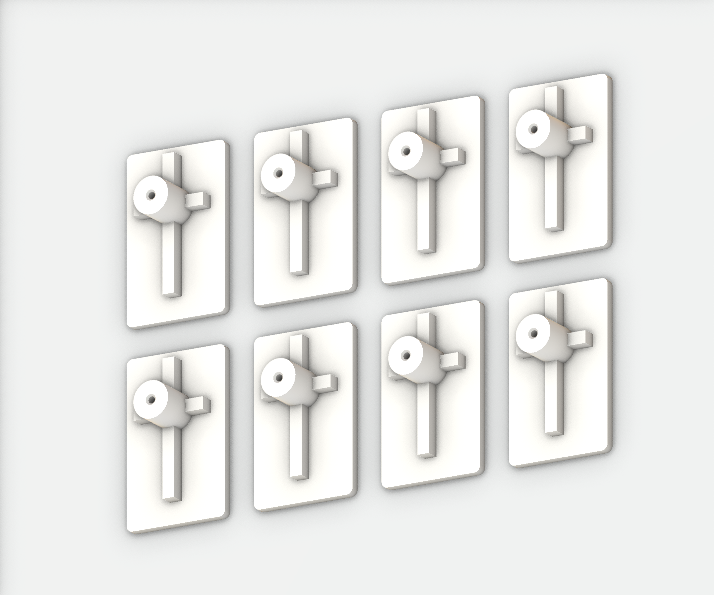
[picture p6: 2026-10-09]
docs/images/S01_mounts.png

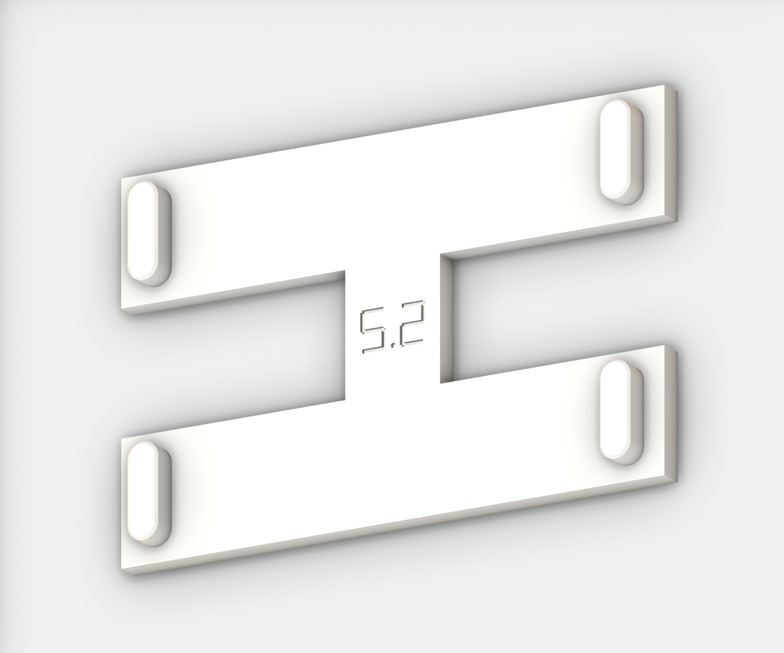
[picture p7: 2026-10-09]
docs/images/S01_jig.png

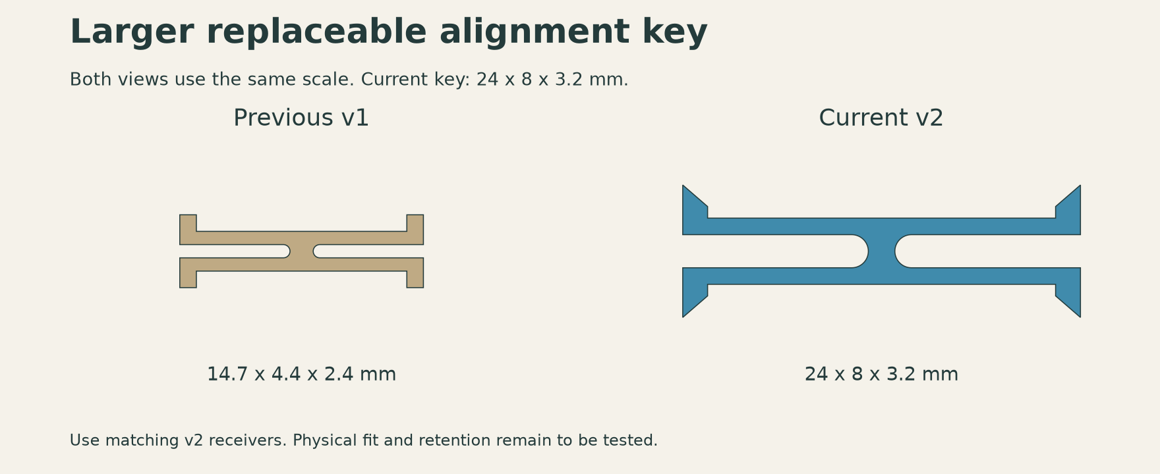
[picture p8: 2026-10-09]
docs/images/key-size-comparison.png

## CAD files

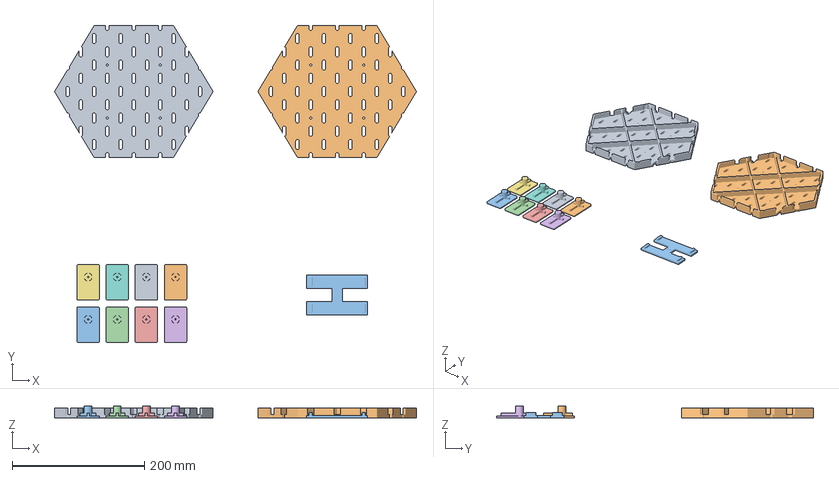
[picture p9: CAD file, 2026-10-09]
PRINT_THIS/S01_complete_kit_PETG_P2S.3mf
546.9 x 479.1 x 18.0 mm
S01_panel_1 x 2
wall_shoe_3x16_pilot_2p2_1 x 8
front_jig_5p2_deep_flat_1

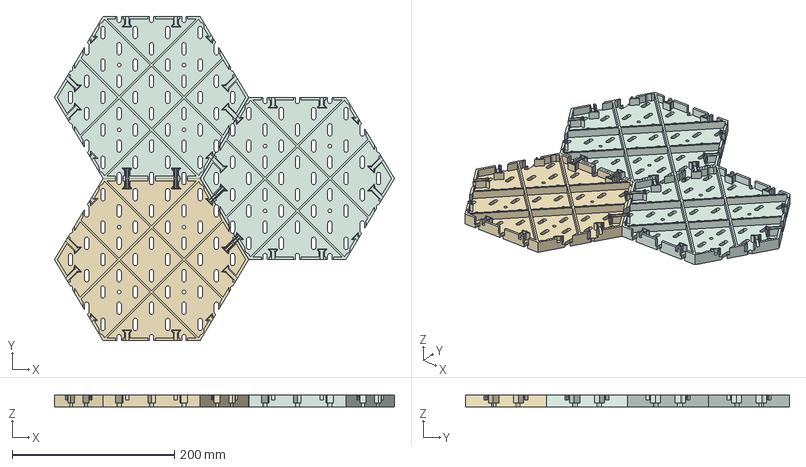
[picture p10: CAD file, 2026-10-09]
models/current/step/three_panels_assembly.step
419.7 x 399.7 x 15.0 mm
new_panel
existing_0
existing_1
key_0
key_1
key_2
key_3

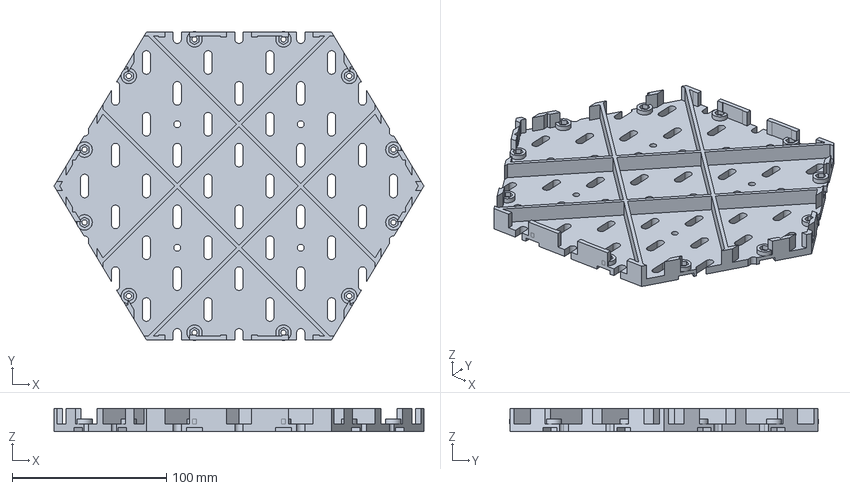
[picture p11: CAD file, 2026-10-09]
analysis/v3/inputs/S01_diamond.step
239.7 x 200.0 x 15.0 mm

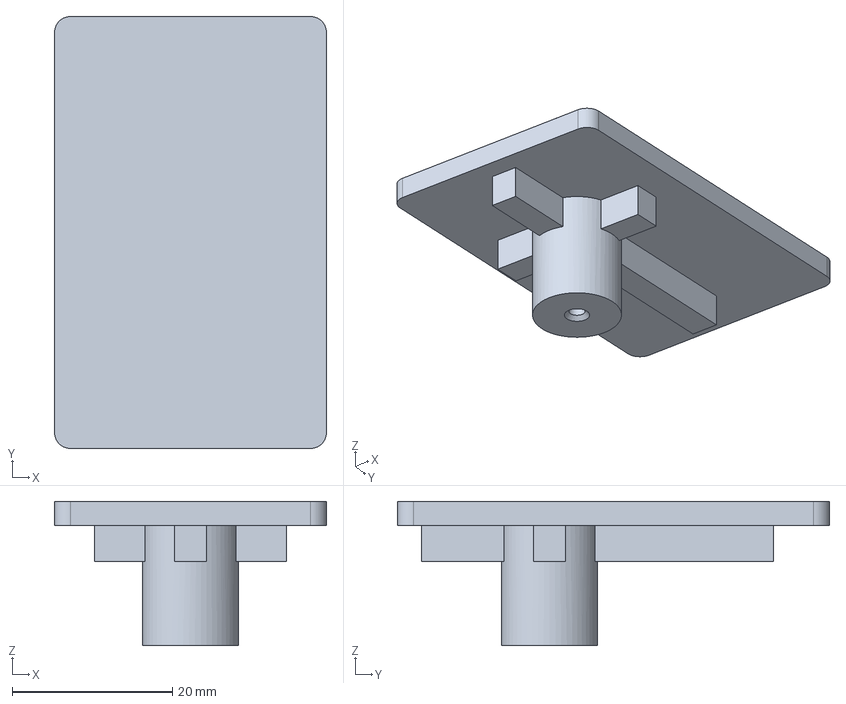
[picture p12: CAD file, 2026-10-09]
cad/S01_wall_mount_2p2.step
34.0 x 54.0 x 18.0 mm

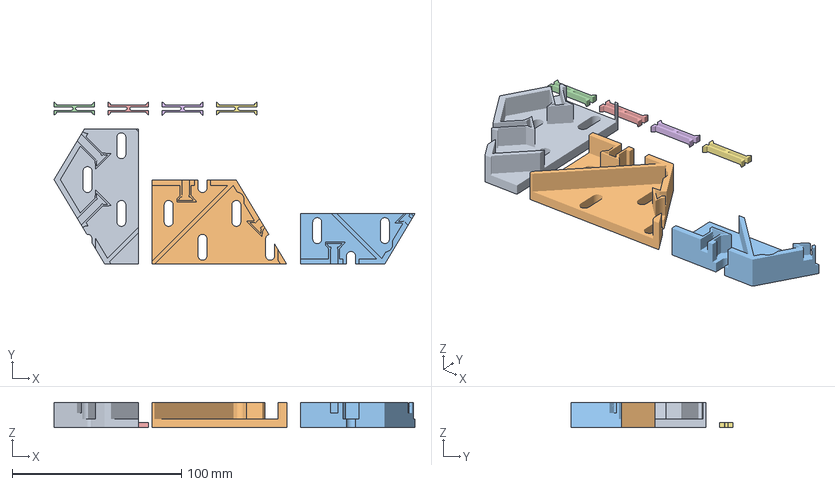
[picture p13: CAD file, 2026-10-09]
models/current/projects/corner_fit_test_24x8x3p2_P2S.3mf
213.5 x 96.0 x 15.0 mm
corner_EXISTING_oblique
corner_NEW
corner_EXISTING_horizontal
spring_key_24x8x3p2 x 4

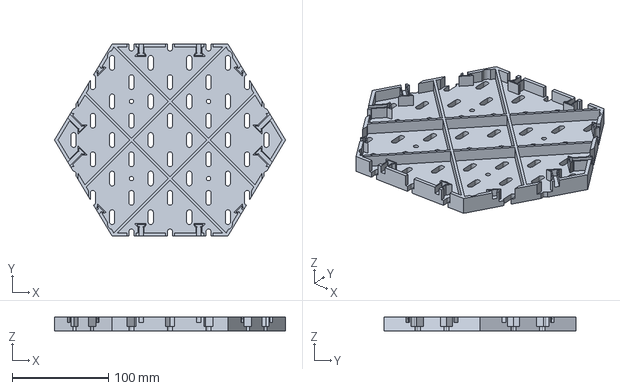
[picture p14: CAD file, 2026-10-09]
models/current/step/S01_hidden_joint_PROTOTYPE.step
239.7 x 199.7 x 15.0 mm

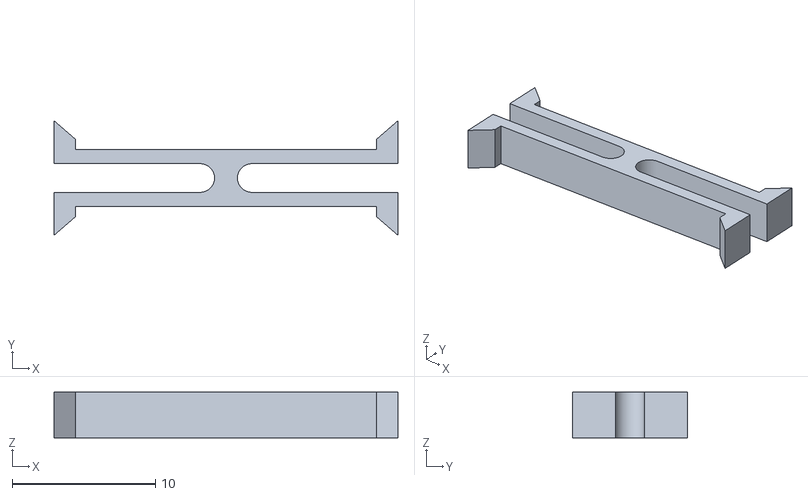
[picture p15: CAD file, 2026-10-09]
models/current/stl/spring_key_24x8x3p2.stl
24.0 x 8.00 x 3.20

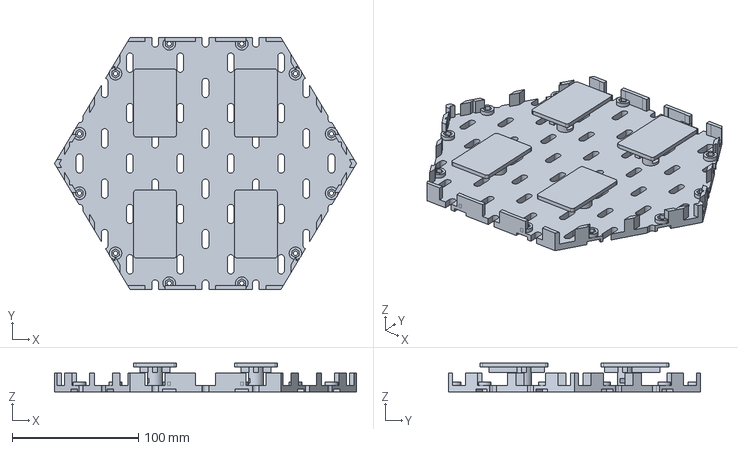
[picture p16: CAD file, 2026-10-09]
analysis/v3/inputs/S01_rim_mounted.step
239.7 x 200.0 x 23.0 mm

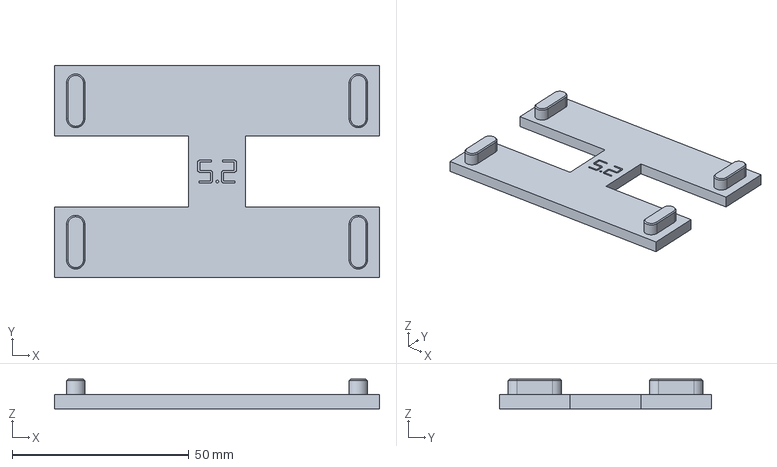
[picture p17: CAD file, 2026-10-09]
cad/S01_alignment_jig_5p2.step
92.0 x 60.0 x 8.40 mm

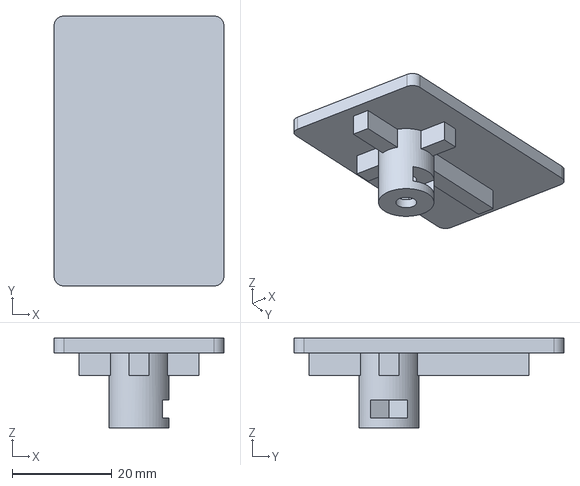
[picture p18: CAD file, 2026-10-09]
models/current/step/wall_shoe_M4_16_to_20.step
34.0 x 54.0 x 18.0 mm

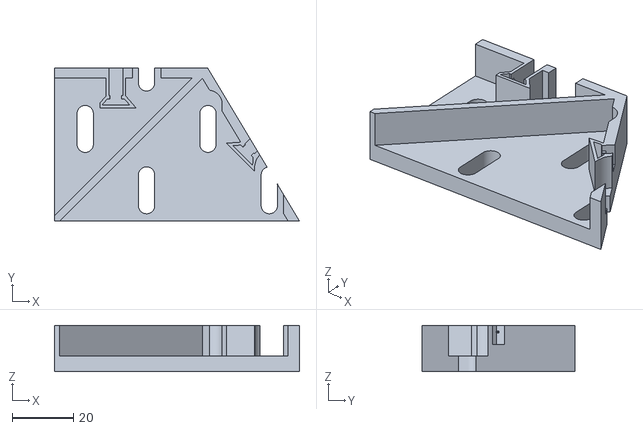
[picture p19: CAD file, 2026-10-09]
models/current/stl/corner_NEW.stl
79.8 x 49.8 x 15.0

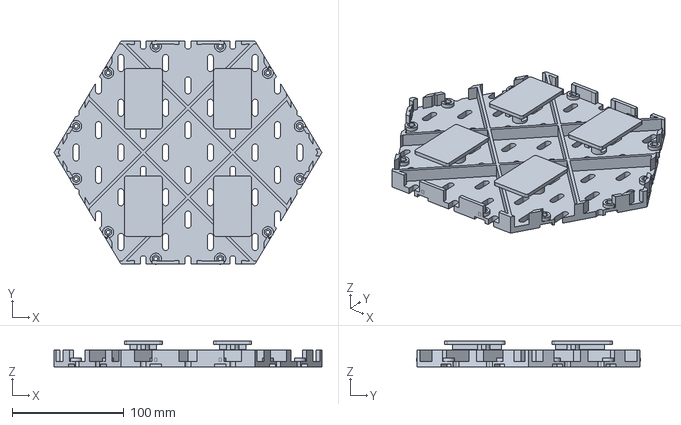
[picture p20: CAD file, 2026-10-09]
analysis/v3/inputs/S01_diamond_mounted.step
239.7 x 200.0 x 23.0 mm

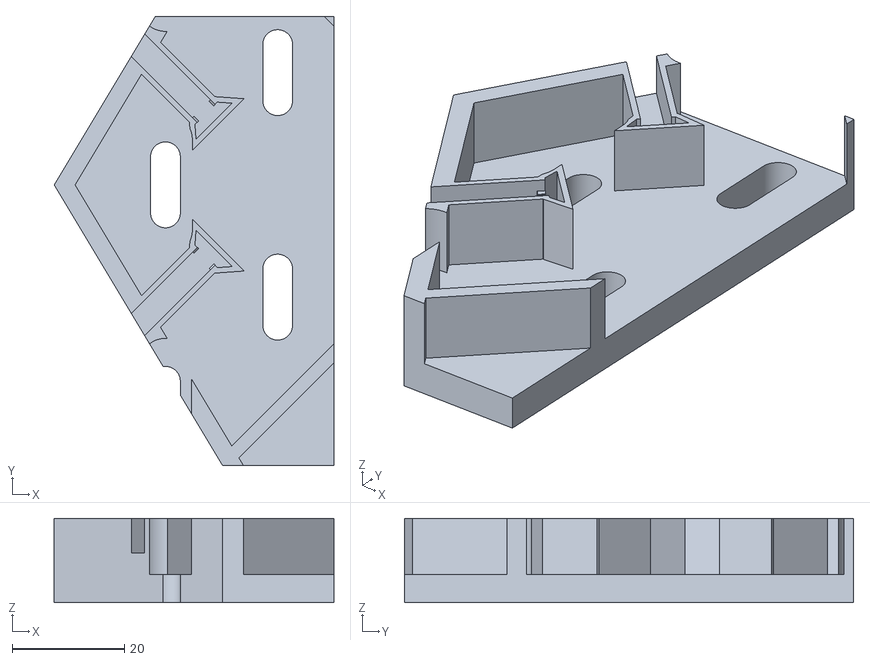
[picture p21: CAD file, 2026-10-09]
models/current/stl/corner_EXISTING_oblique.stl
49.8 x 80.0 x 15.0

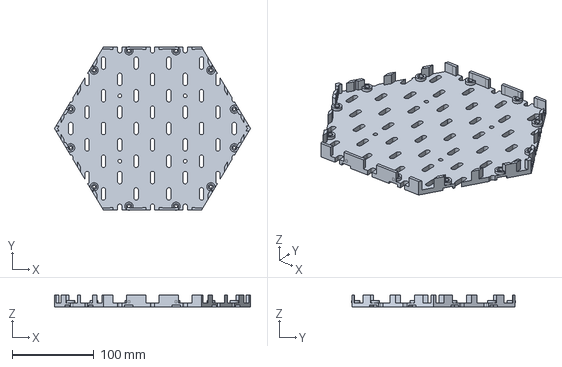
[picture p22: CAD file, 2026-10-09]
analysis/v3/inputs/S01_rim.step
239.7 x 200.0 x 15.0 mm

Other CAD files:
models/current/projects/corner_fit_test_geometry.3mf
PRINT_THIS/S01_wall_mount_2p2.stl
cad/S01_with_four_shoes.step
PRINT_THIS/S01_alignment_jig_5p2.stl
PRINT_THIS/S01_panel.stl
PRINT_THIS/S01_panel_PLA_P2S.3mf
analysis/v3/inputs/S01_long.step
analysis/v3/inputs/S01_long_mounted.step
archive/experiments/S01_S02_S06/S01_ribbed.stl
archive/experiments/S01_S02_S06/S02_ribbed.stl
archive/experiments/S01_S02_S06/S06_ribbed.stl
archive/experiments/hex_connectors_v1/S01_connectable.stl
archive/experiments/hex_connectors_v1/S02_connectable.stl
archive/experiments/hex_connectors_v1/S06_connectable.stl
archive/experiments/hex_connectors_v1/fit_diagonal_1.stl
archive/experiments/hex_connectors_v1/fit_diagonal_2.stl
archive/experiments/hex_connectors_v1/fit_straight_1.stl
archive/experiments/hex_connectors_v1/fit_straight_2.stl
archive/experiments/hex_connectors_v1/key_loose.stl
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

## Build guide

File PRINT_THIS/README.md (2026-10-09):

# Print these files

This folder contains only the current S01 version.

| File | Contents |
|---|---|
| [S01_complete_kit_PETG_P2S.3mf](S01_complete_kit_PETG_P2S.3mf) | Two panel plates, eight PETG mounts and one flat PETG jig |
| [S01_panel_PLA_P2S.3mf](S01_panel_PLA_P2S.3mf) | The same panel, with PLA settings |
| [S01_panel.stl](S01_panel.stl) | Panel geometry for your own slicing |
| [S01_wall_mount_2p2.stl](S01_wall_mount_2p2.stl) | Wall mount with the selected 2.2 mm pilot |
| [S01_alignment_jig_5p2.stl](S01_alignment_jig_5p2.stl) | Flat jig with 5.2 × 15.2 × 4.4 mm locators |

Native projects target P2S / 0.4 mm, 0.2 mm layers, four walls and 100% infill. No supports. Choose the PETG or PLA panel as needed; mounts and jig use PETG. Keep scale at 100%.

The 5.2 mm PETG strip fit was selected after printing. The deeper jig and selected 2.2 mm screw pilot are the next full-size assembly test.

[Printing and assembly](../docs/assembly.md) · [Hardware](../docs/hardware.md) · [Editable STEP](../cad/) · [Verification](../verification/current/)

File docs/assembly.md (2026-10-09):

# Full-size test print and assembly

The next print is the full S01 panel kit. The 5.2 mm PETG locator width was selected from the printed strip trial; the user selected a 2.2 mm wall-shoe pilot and requested no further small calibration prints.

## Choose the print project

Open [S01_full_test_kit_P2S_PETG_flat_jig.3mf](../PRINT_THIS/S01_complete_kit_PETG_P2S.3mf) for the complete PETG kit:

| Plate | Contents | Estimated time | Material |
|---|---|---:|---:|
| 1 | One S01 panel | 6 h 45 min | 238.87 g PETG |
| 2 | A second identical S01 panel | 6 h 45 min | 238.87 g PETG |
| 3 | Eight wall shoes, 2.2 mm pilot | 2 h 39 min | 77.07 g PETG |
| 4 | One flat alignment jig, 5.2 mm fit | 39 min | 20.96 g PETG |

For a PLA panel, use [S01_panel_P2S_PLA.3mf](../PRINT_THIS/S01_panel_PLA_P2S.3mf): 6 h 43 min / 240.59 g. It has exactly the same panel geometry. This is an alternative to a PETG panel plate, not an additional required panel. To compare materials, print one panel from each project and the PETG hardware plates.

All projects target P2S / 0.4 mm, 0.2 mm layers, four walls, 100% infill and Arachne. They use resolved Generic PLA and Generic PETG presets from the installed Bambu Studio distribution. Match the selected material preset and plate type to the actual spool and bed before printing. Keep scale at 100%.

The installed Bambu Studio 2.8 command-line slicer failed when switching filament indices between PLA and PETG plates in one run. The delivered projects each use one material and were independently sliced and checked. No G-code was manually patched.

## Print orientation and supports

- Panels: flat visible face on the bed, ribs upward. No supports.
- Wall shoes: broad adhesive base on the bed, post and pilot upward. No supports.
- Jig: flat body face on the bed, locators upward. No supports.

The jig locators are 5.2 × 15.2 mm and project 4.4 mm, with a 0.4 mm tip lead-in. They stop 0.6 mm before the back of the 5 mm panel face. The body is flat; the requested pull knob was removed to eliminate support printing.

## Mount each panel

1. Use four printed shoes and four purchased pointed 3 × 16 mm self-tapping screws per panel. No nuts or washers are specified.
2. Place the shoes behind the four dedicated 3.4 mm mounting holes. On the upper pair, the longer part of the adhesive base points upward; rotate the lower pair 180° so it points downward.
3. Drive each screw through the panel into the 2.2 mm pilot using a hand tool. Tighten only until the head seats and the shoe no longer moves. Do not drive a bare screw fully into an uncovered shoe: the panel's 5 mm thickness is part of the screw-length stack.
4. Apply a 30 × 50 mm tape strip to each 34 × 54 mm base.
5. Position the first panel. For its neighbour, support the new panel by hand, bring it close to the installed panel's face plane, and engage two jig locators in each panel before the adhesive contacts the wall. Use complete slots; keep the locator ovals vertical for every seam.
6. Press the new panel's shoes to the wall with both panel faces seated against the jig. Hold the panels in place and pull the jig straight forward by its central spine or edges. The jig is an alignment aid; each panel remains supported by its own four shoes.

The nominal contour gap is 0.3 mm. Do not squeeze the edges together to eliminate it: the hole lattice sets the panel-centre positions.

## What this full-size test should establish

Check the increased jig insertion depth and removal, screw seating in the selected pilot, actual accessory movement behind the rim, and accessories spanning two rows or crossing a seam. The confirmed strip fit does not establish the full four-point jig fit on both PLA and PETG panels. The 2.2 mm pilot is user-selected and has not yet been physically tried with the purchased screws.

The tape is an unverified 30 mm product and the wall is wallpaper. Adhesive retention and a full-panel load rating remain unestablished. The historical 3 kg / 100 mm stiffness calculation is an earlier-geometry comparison, not a rating for this kit.

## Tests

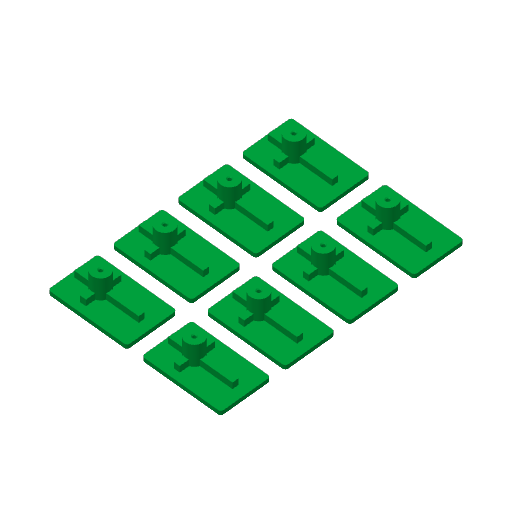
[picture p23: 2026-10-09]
verification/current/images/PETG_plate_3.png

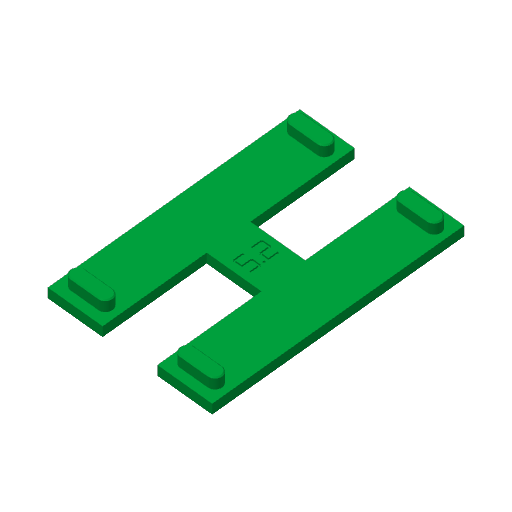
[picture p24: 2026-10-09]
verification/current/images/PETG_plate_4.png

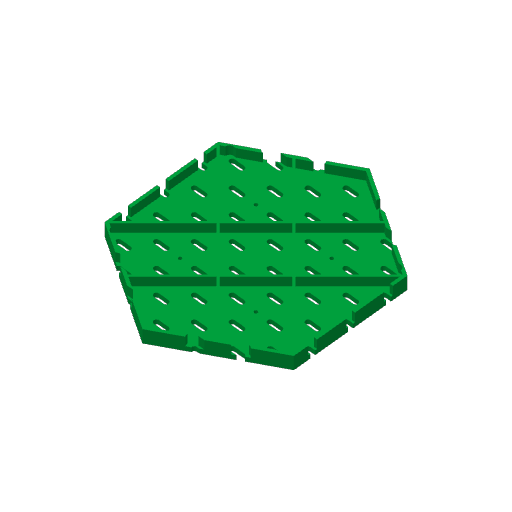
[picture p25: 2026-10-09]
verification/current/images/PETG_plate_1.png

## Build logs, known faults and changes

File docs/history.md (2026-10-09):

# Design history

All items below describe earlier experiments. The active implementation is under `src/skadis_hex`; the printable full-size kit is under `PRINT_THIS`.

| Stage | Result and decision |
|---|---|
| Initial 240 × 200 panel with whole slots only | Too many omitted edge slots; rejected |
| Candidate C, 160 × 240 | Preserved a whole-slot layout but deviated too much from the preferred hex shape |
| Symmetric search: S01, S02, S06 | Allowed split boundary slots; lattice reconstruction checked in a 3 × 3 assembly |
| Dense ribbed S01/S02/S06 | User's printed sample felt overbuilt; reduced rib count requested |
| Small rear butterfly keys | Printed fit varied, markings were hard to read, rear caps added depth, and adding wall-mounted neighbours was inconvenient; rejected |
| v3 front screw bridges and four adhesive shoes | Shoe positions and independent panel mounting retained; front seam bridges superseded |
| Four-diagonal layout and v3 stiffness study | Selected for the next prototype; user accepted the predicted deflections as a useful comparison |
| v4 removable registration jig | Used working slots during positioning; user preferred hidden permanent alignment in the perimeter |
| Continuous perimeter with local hook relief | Replaced the excessive 16 × 34 mm rear clearance boxes; extra downward hook travel requested |
| Hidden joint v1, 14.7 × 4.4 × 2.4 key | Geometric insertion prototype; user requested a larger handling size |
| Hidden joint v2, 24 × 8 × 3.2 key | PETG physical test failed retention and showed excessive play. Permanent keys, dowels and receivers were subsequently abandoned |
| Missing triangular coupon patch | A crop split off a small face island and the export kept only the largest solid. Crop boundaries moved; filtering removed; regression check now preserves the patch |
| Removable front jig, revisited | User approved two horizontal bars and a central spine, four short locators on an 80 × 40 grid. Open sides clear wall screw heads. Three labelled PETG fit strips precede the full jig |

The final kit uses 4.4 mm-deep locators with the selected 5.2 mm width. A pull knob was briefly added, then removed at the user’s request to eliminate supports. Panels have PLA and PETG project variants; hardware uses PETG.

## Retained findings

- Preserve one global slot lattice, including two-row accessory spacing.
- Keep the nominal tile translations fixed when adding a seam gap.
- Preserve the preferred S01 outline and 180° use.
- Keep four diagonal ribs and a substantially continuous perimeter.
- Leave room for the hook's downward movement behind boundary slots.
- Every tile has four independent wall mounts; inter-panel features serve alignment.
- Adding a tile beside multiple existing neighbours must use a common approach toward the wall.
- Use a removable front jig for positioning; leave no permanent inter-panel hardware.

## Remaining physical work

- The 5.2 mm strip fit was selected. Check the deeper full jig across both seam orientations during the full-size assembly.
- The user selected a 2.2 mm pilot. Check screw seating during the full-size assembly.
- Check actual printed accessories, particularly two-row accessories and seam-spanning mounts.
- Check the local rear hook relief and front screw-head clearance.
- Test the chosen tape on the actual wallpaper over time.
- Release a full printable current panel only after the fit prototype is accepted.

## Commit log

2026-10-09 Organize parametric panel project and current prototype
    [S01_connectable.stl, S01_diamond.step, S01_diamond_mounted.step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]
2026-10-09 Deliver the complete S01 print kit with clearly marked final files (#1)
    * Add nominal 3x16 self-tapping mount trials and record key fit failure
    * Add removable front alignment jig and PETG fit strips
    * Deliver complete S01 print kit with flat support-free alignment jig
    * Expose final print files clearly and archive superseded prototypes
    * Refresh archived checksums after documentation relocation
    ---------
    [S01_alignment_jig_5p2.step, S01_alignment_jig_5p2.stl, S01_complete_kit_PETG_P2S.3mf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]
2026-10-09 Clarify assembly seams and label two S01 panels (#3)
